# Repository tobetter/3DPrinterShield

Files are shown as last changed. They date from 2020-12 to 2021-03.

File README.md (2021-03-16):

## 3D Printer Shield 

"3D Printer Shield" is a board to run 3D printer using ODROID single board
computer, technically this board is designed to control the motor driver
modules with TMC2209 (UART) or TMC2130 (SPI) through the on-board GPIO
headers without an additional processessor.

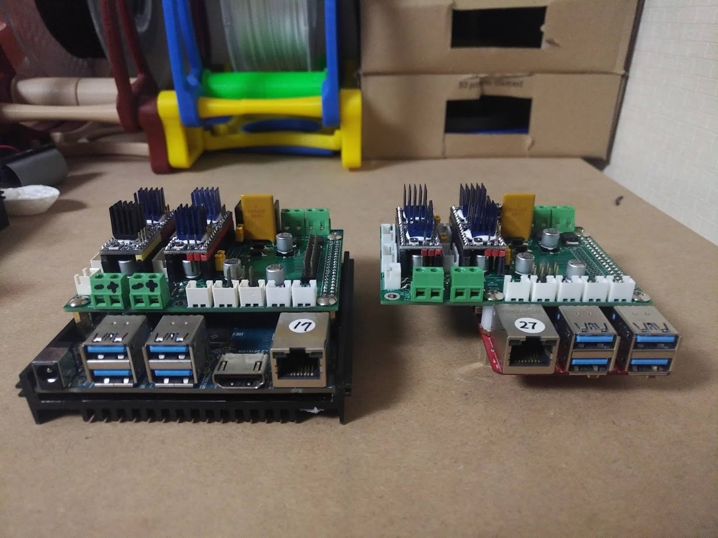
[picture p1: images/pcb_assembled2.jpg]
3D Printer Shiled on ODROID-N2Plus and ODROID-C4


Originally this project is started to use RAMPS 1.6, but has changed to design
a new board since board connection is quite different.

(http://www.youtube.com/watch?v=o2U3yanucio "")

The board has been tested with Ender-3 and runs by Klipper.

(http://www.youtube.com/watch?v=SXoTmYS2FU0 "")

Then later, I've built an OS image to run Klipper on ODROID-C4 and the image
can be downloaded from [the link](https://bit.ly/3ppd9lL)

(http://www.youtube.com/watch?v=UwoKeeDlM0k "")

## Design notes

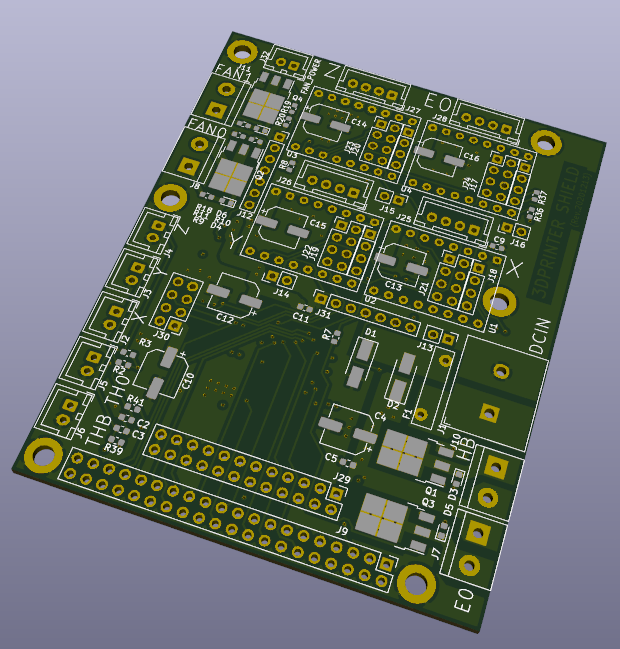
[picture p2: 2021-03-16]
images/pcb_preview.png

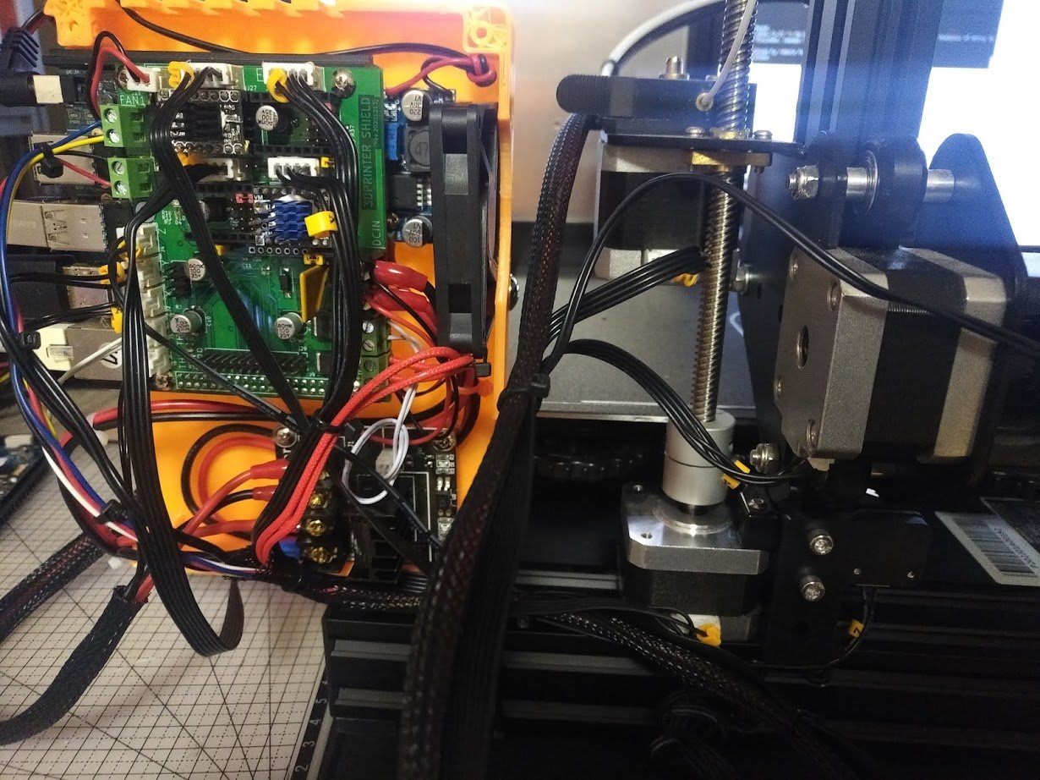
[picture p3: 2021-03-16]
images/3dprintershield_ender-3.jpg

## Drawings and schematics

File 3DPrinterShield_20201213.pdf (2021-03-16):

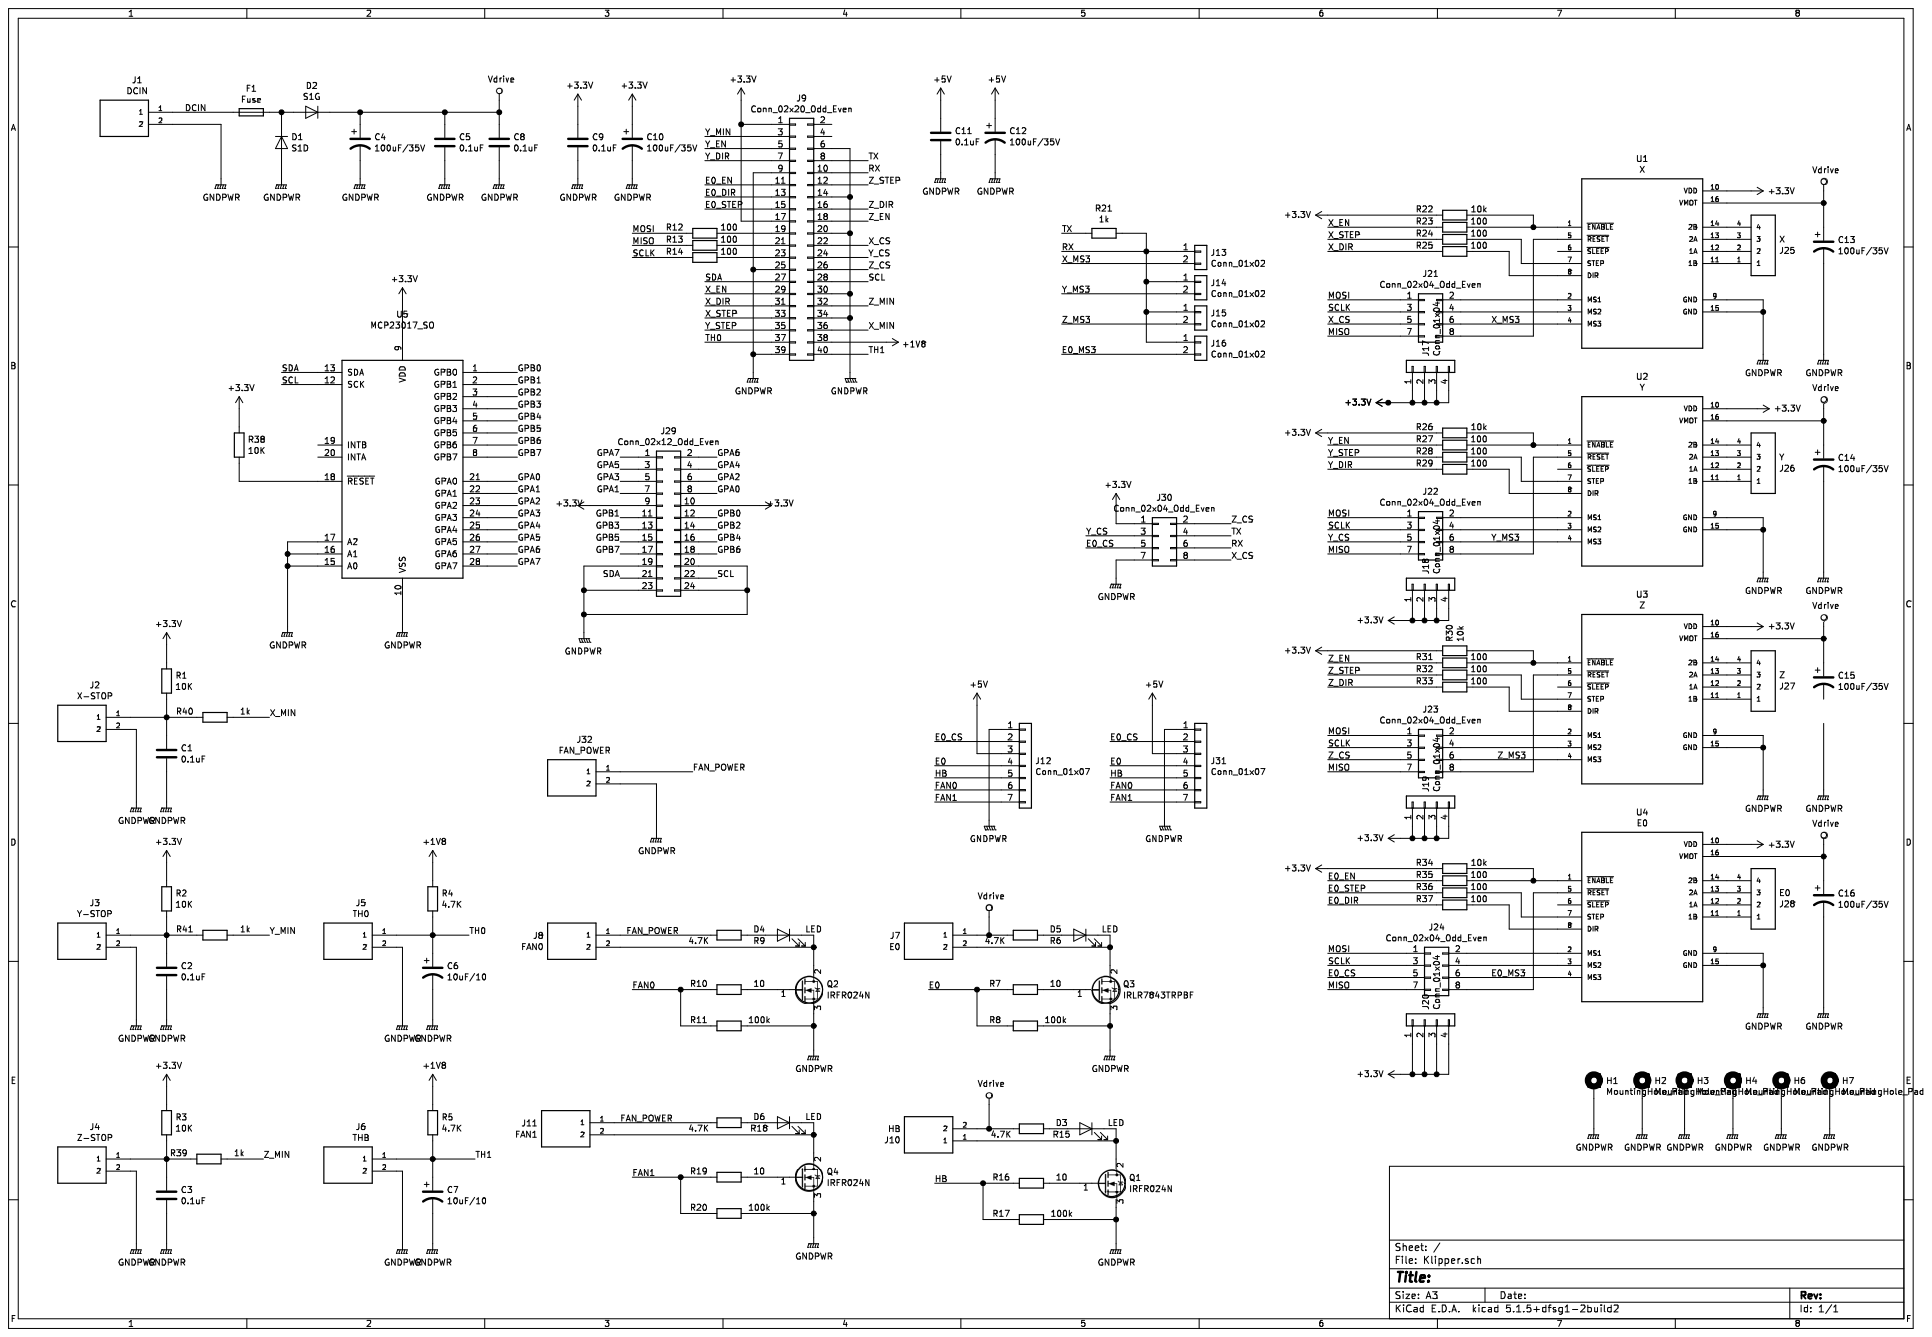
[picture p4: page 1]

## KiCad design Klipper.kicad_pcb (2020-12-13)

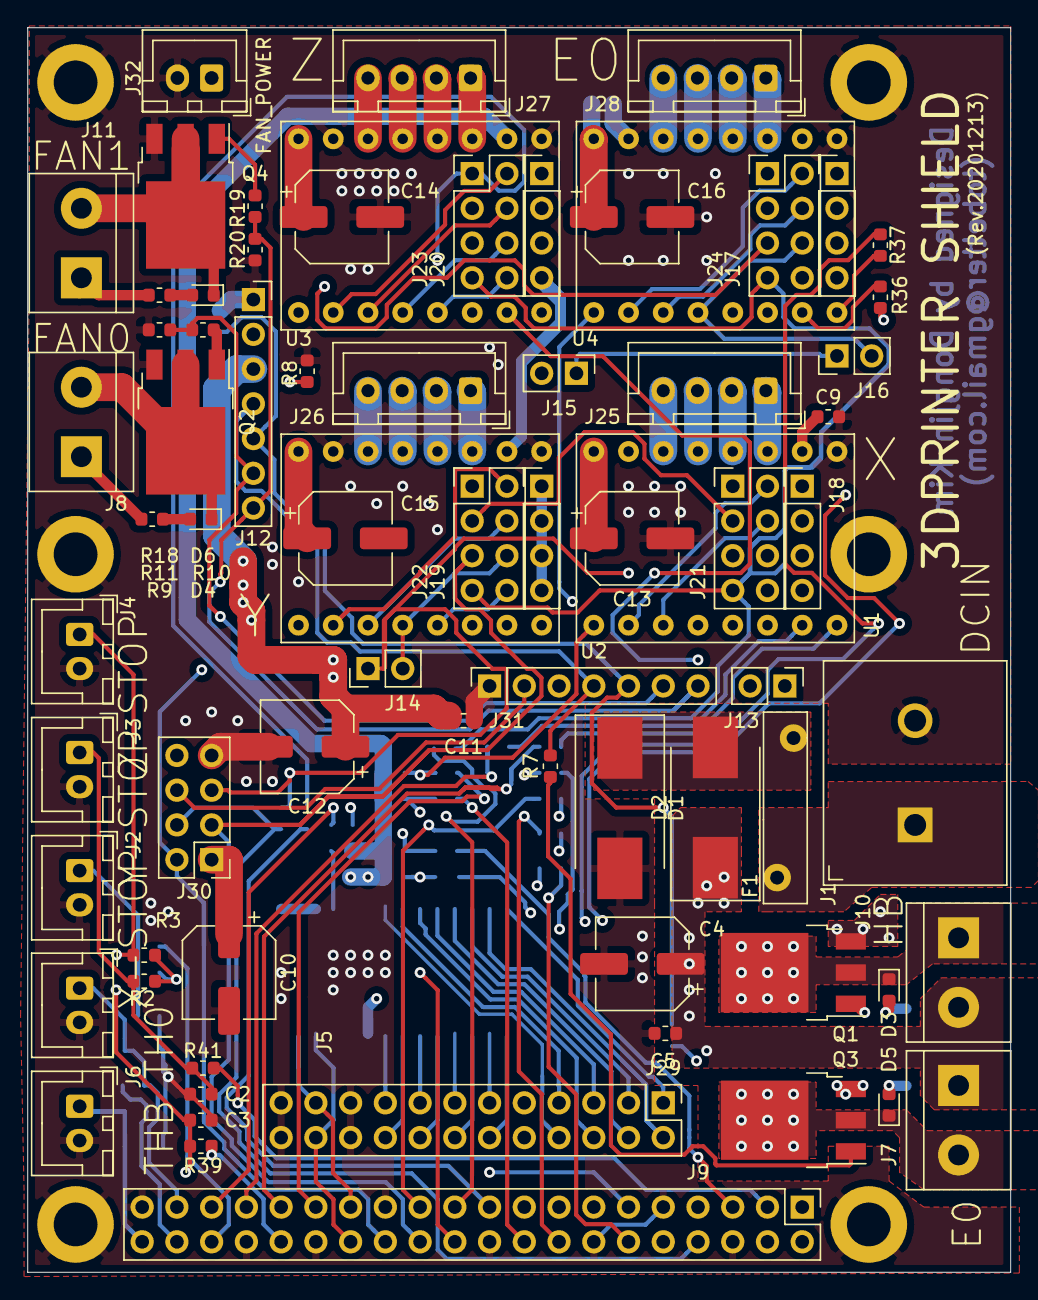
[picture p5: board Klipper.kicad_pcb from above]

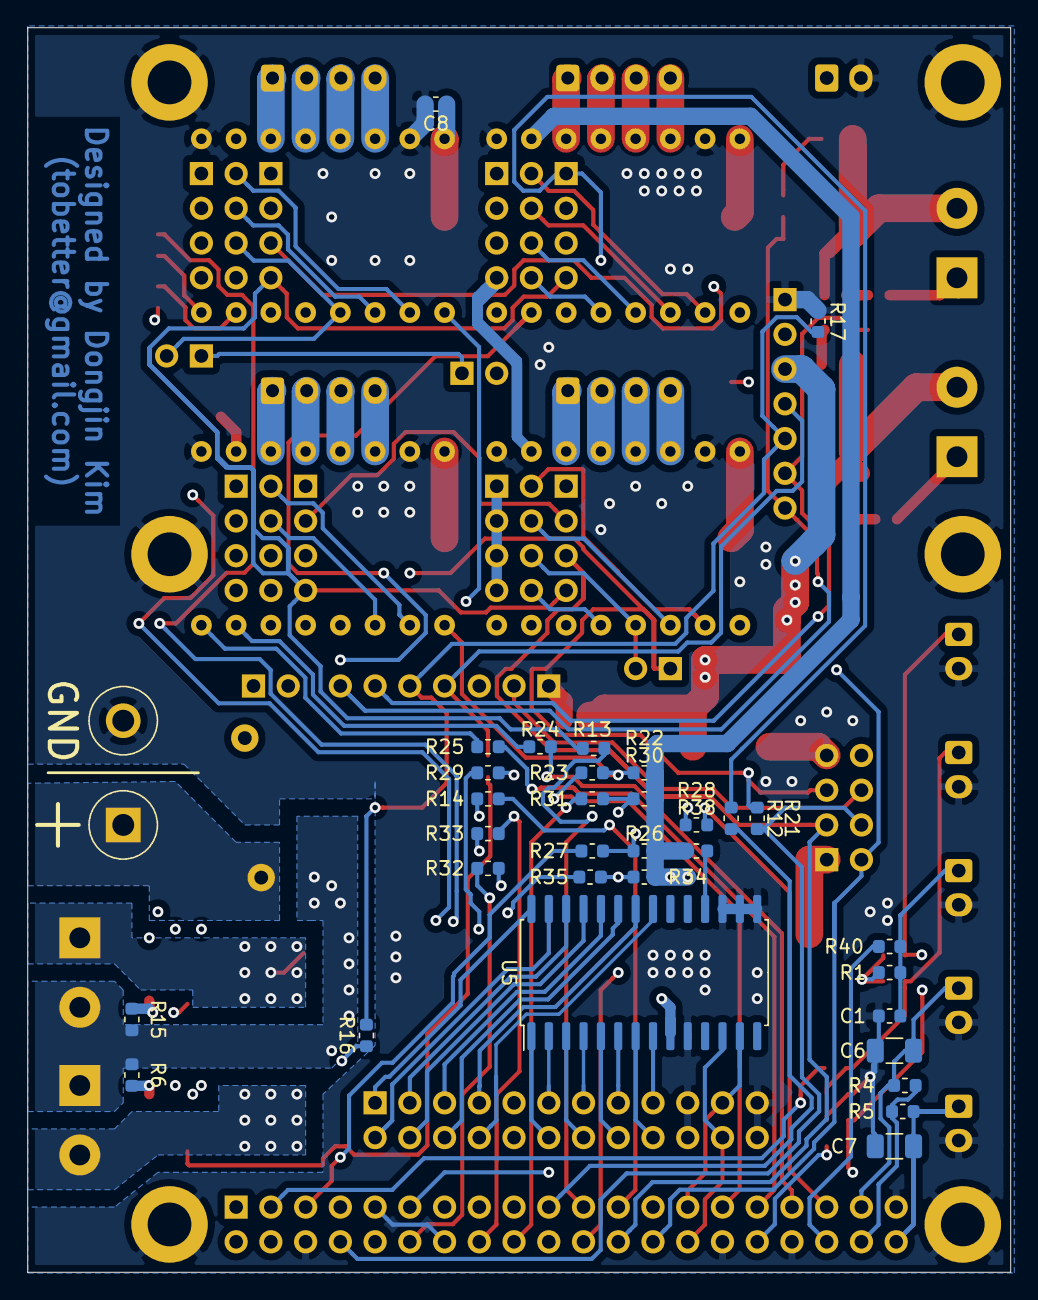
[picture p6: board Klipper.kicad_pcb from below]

Board: 4 copper layers, 71.9 x 91.0 mm, 111 parts (32 on the bottom side), 119 nets.

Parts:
C1, C2, C3, C5, C8, C9, C11: 0.1uF; C_0603_1608Metric
C4, C10, C12, C13, C14, C15, C16: 100uF/35V; CP_Elec_6.3x5.9
C6, C7: 10uF/10; C_1206_3216Metric
D1: S1D; D_SMC_Handsoldering
D2: SS54CF; D_SMC_Handsoldering
D3, D4, D5, D6: LED; LED_0603_1608Metric
F1: Fuse; FRU500-30F
H1, H2, H3, H4, H6, H7: MountingHole_Pad; MountingHole_3.2mm_M3_DIN965_Pad
J1: DCIN; TerminalBlock_BR_762C_P7.62mm
J2: X-STOP; JST_XH_B2B-XH-A_1x02_P2.50mm_Vertical
J3: Y-STOP; JST_XH_B2B-XH-A_1x02_P2.50mm_Vertical
J4: Z-STOP; JST_XH_B2B-XH-A_1x02_P2.50mm_Vertical
J5: TH0; JST_XH_B2B-XH-A_1x02_P2.50mm_Vertical
J6: THB; JST_XH_B2B-XH-A_1x02_P2.50mm_Vertical
J7: E0; TerminalBlock_bornier-2_P5.08mm
J8: FAN0; TerminalBlock_bornier-2_P5.08mm
J9: Conn_02x20_Odd_Even; PinHeader_2x20_P2.54mm_Vertical
J10: HB; TerminalBlock_bornier-2_P5.08mm
J11: FAN1; TerminalBlock_bornier-2_P5.08mm
J12, J31: Conn_01x07; PinSocket_1x07_P2.54mm_Vertical
J13, J14, J15, J16: Conn_01x02; PinHeader_1x02_P2.54mm_Vertical
J17, J18, J19, J20: Conn_01x04; PinHeader_1x04_P2.54mm_Vertical
J21, J22, J23, J24, J30: Conn_02x04_Odd_Even; PinHeader_2x04_P2.54mm_Vertical
J25: X; JST_XH_B4B-XH-A_1x04_P2.50mm_Vertical
J26: Y; JST_XH_B4B-XH-A_1x04_P2.50mm_Vertical
J27: Z; JST_XH_B4B-XH-A_1x04_P2.50mm_Vertical
J28: E0; JST_XH_B4B-XH-A_1x04_P2.50mm_Vertical
J29: Conn_02x12_Odd_Even; PinHeader_2x12_P2.54mm_Vertical
J32: FAN_POWER; JST_XH_B2B-XH-A_1x02_P2.50mm_Vertical
Q1, Q2, Q4: IRFR024N; TO-252-3_TabPin2
Q3: IRLR7843TRPBF; TO-252-3_TabPin2
R1, R2, R3, R38: 10K; R_0603_1608Metric
R4, R5, R6, R9, R15, R18: 4.7K; R_0603_1608Metric
R7, R10, R16, R19: 10; R_0603_1608Metric
R8, R11, R17, R20: 100k; R_0603_1608Metric
R12, R13, R14, R23, R24, R25, R27, R28, R29, R31, R32, R33, R35, R36, R37: 100; R_0603_1608Metric
R21, R39, R40, R41: 1k; R_0603_1608Metric
R22, R26, R30, R34: 10k; R_0603_1608Metric
U1: X; MOTOR_CARRIER
U2: Y; MOTOR_CARRIER
U3: Z; MOTOR_CARRIER
U4: E0; MOTOR_CARRIER
U5: MCP23017_SO; SOIC-28W_7.5x17.9mm_P1.27mm

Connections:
+1V8: J9.38, R4.1, R5.1
+3V3: C9.1, C10.1, J9.1, J9.17, J17.1, J17.2, J17.3, J17.4, J18.1, J18.2, J18.3, J18.4, J19.1, J19.2, J19.3, J19.4, J20.1, J20.2, J20.3, J20.4, J29.9, J29.10, J30.1, R1.1, R2.1, R3.1, R22.2, R26.2, R30.1, R34.2, R38.1, U1.10, U2.10, U3.10, U4.10, U5.9
+5V: C11.1, C12.1, J12.3, J31.3
/DCIN: F1.2, J1.1
/E0: J12.4, J31.4, R7.2, R8.2
/E0_CS: J12.2, J24.5, J30.6, J31.2
/E0_DIR: J9.13, R37.2
/E0_EN: J9.11, R35.2
/E0_MS3: J16.2, J24.6, U4.4
/E0_STEP: J9.15, R36.2
/FAN0: J12.6, J31.6, R10.2, R11.2
/FAN1: J12.7, J31.7, R19.2, R20.2
/FAN_POWER: J8.1, J11.1, J32.1, R9.1, R18.1
/GPA0: J29.8, U5.21
/GPA1: J29.7, U5.22
/GPA2: J29.6, U5.23
/GPA3: J29.5, U5.24
/GPA4: J29.4, U5.25
/GPA5: J29.3, U5.26
/GPA6: J29.2, U5.27
/GPA7: J29.1, U5.28
/GPB0: J29.12, U5.1
/GPB1: J29.11, U5.2
/GPB2: J29.14, U5.3
/GPB3: J29.13, U5.4
/GPB4: J29.16, U5.5
/GPB5: J29.15, U5.6
/GPB6: J29.18, U5.7
/GPB7: J29.17, U5.8
/HB: J12.5, J31.5, R16.2, R17.2
/MISO: J21.7, J22.7, J23.7, J24.7, R13.2
/MOSI: J21.1, J22.1, J23.1, J24.1, R12.2
/RX: J9.10, J13.1, J14.1, J15.1, J16.1, J30.5, R21.2
/SCL: J9.28, J29.22, U5.12
/SCLK: J21.3, J22.3, J23.3, J24.3, R14.2
/SDA: J9.27, J29.21, U5.13
/TH0: C6.1, J5.1, J9.37, R4.2
/TH1: C7.1, J6.1, J9.40, R5.2
/TX: J9.8, J30.4, R21.1
/X_CS: J9.22, J21.5, J30.8
/X_DIR: J9.31, R25.2
/X_EN: J9.29, R23.2
/X_MIN: J9.36, R40.1
/X_MS3: J13.2, J21.6, U1.4
/X_STEP: J9.33, R24.2
/Y_CS: J9.24, J22.5, J30.3
/Y_DIR: J9.7, R29.2
/Y_EN: J9.5, R27.2
/Y_MIN: J9.3, R41.1
/Y_MS3: J14.2, J22.6, U2.4
/Y_STEP: J9.35, R28.2
/Z_CS: J9.26, J23.5, J30.2
/Z_DIR: J9.16, R33.2
/Z_EN: J9.18, R31.2
/Z_MIN: J9.32, R39.1
/Z_MS3: J15.2, J23.6, U3.4
/Z_STEP: J9.12, R32.2
GNDPWR: C1.2, C2.2, C3.2, C4.2, C5.2, C6.2, C7.2, C8.2, C9.2, C10.2, C11.2, C12.2, C13.2, C14.2, C16.2, D1.2, H1.1, H2.1, H3.1, H4.1, H6.1, H7.1, J1.2, J2.2, J3.2, J4.2, J5.2, J6.2, J9.6, J9.9, J9.14, J9.20, J9.25, J9.30, J9.34, J9.39, J12.1, J29.19, J29.20, J29.23, J29.24, J30.7, J31.1, J32.2, Q1.3, Q2.3, Q3.3, Q4.3, R8.1, R11.1, R17.1, R20.1, U1.9, U1.15, U2.9, U2.15, U3.9, U3.15, U4.9, U4.15, U5.10, U5.15, U5.16, U5.17
unnamed: C1.1, J2.1, R1.2, R40.2
unnamed: C2.1, J3.1, R2.2, R41.2
unnamed: C3.1, J4.1, R3.2, R39.2
unnamed: D1.1, D2.2, F1.1
unnamed: D3.1, J10.1, Q1.2
unnamed: D3.2, R15.2
unnamed: D4.1, J8.2, Q2.2
unnamed: D4.2, R9.2
unnamed: D5.1, J7.2, Q3.2
unnamed: D5.2, R6.2
unnamed: D6.1, J11.2, Q4.2
unnamed: D6.2, R18.2
unnamed: J9.19, R12.1
unnamed: J9.21, R13.1
unnamed: J9.23, R14.1
unnamed: J21.2, U1.2
unnamed: J21.4, U1.3
unnamed: J21.8, U1.5
unnamed: J22.2, U2.2
unnamed: J22.4, U2.3
unnamed: J22.8, U2.5
unnamed: J23.2, U3.2
unnamed: J23.4, U3.3
unnamed: J23.8, U3.5
unnamed: J24.2, U4.2
unnamed: J24.4, U4.3
unnamed: J24.8, U4.5
unnamed: J25.1, U1.11
unnamed: J25.2, U1.12
unnamed: J25.3, U1.13
unnamed: J25.4, U1.14
unnamed: J26.1, U2.11
unnamed: J26.2, U2.12
unnamed: J26.3, U2.13
unnamed: J26.4, U2.14
unnamed: J27.1, U3.11
unnamed: J27.2, U3.12
unnamed: J27.3, U3.13
unnamed: J27.4, U3.14
unnamed: J28.1, U4.11
unnamed: J28.2, U4.12
unnamed: J28.3, U4.13
unnamed: J28.4, U4.14
unnamed: Q1.1, R16.1
unnamed: Q2.1, R10.1
unnamed: Q3.1, R7.1
unnamed: Q4.1, R19.1
unnamed: R22.1, R23.1, U1.1
unnamed: R24.1, U1.7
unnamed: R25.1, U1.8
unnamed: R26.1, R27.1, U2.1
unnamed: R28.1, U2.7
unnamed: R29.1, U2.8
unnamed: R30.2, R31.1, U3.1
unnamed: R32.1, U3.7
unnamed: R33.1, U3.8
unnamed: R34.1, R35.1, U4.1
unnamed: R36.1, U4.7
unnamed: R37.1, U4.8
unnamed: R38.2, U5.18
Vdrive: C4.1, C5.1, C8.1, C13.1, C14.1, C15.1, C16.1, D2.1, J7.1, J10.2, R6.1, R15.1, U1.16, U2.16, U3.16, U4.16

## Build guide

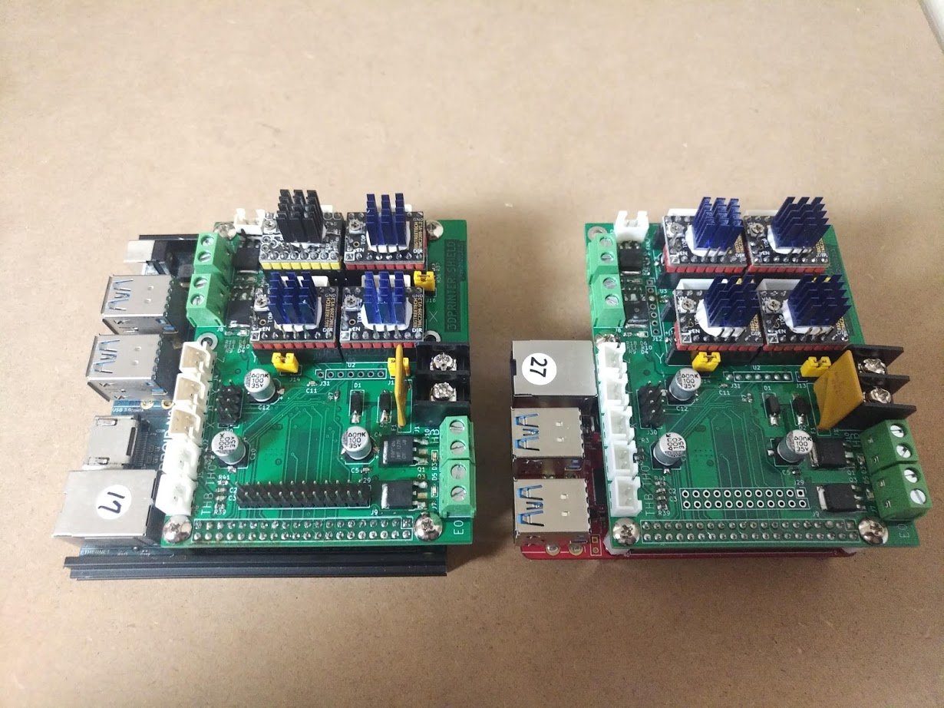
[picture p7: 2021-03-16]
images/pcb_assembled1.jpg

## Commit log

2020-12-13 First commit for new design
    [Klipper.kicad_pcb, Klipper.sch]
2021-03-16 Add Gerber files
    [Klipper-B_Cu.gbr, Klipper-B_Mask.gbr, Klipper-B_Paste.gbr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]
2021-03-16 Add schematic in PDF
